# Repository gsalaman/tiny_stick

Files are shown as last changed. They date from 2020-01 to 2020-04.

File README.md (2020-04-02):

# Tiny Stick
Hardware design for a line of 8 surface-mount WS2812C LEDs

tinystick

# Configurations
## UNO (or other external processor)
You can use the 8 RGB LEDs with any Arduino capable processor.  Supply 5v, Gnd, and your Data Input via the "external input" ports on the bottom-left of the board.

You can chain together multiple sticks by using the "external output" port on the bottom-right.
## Tiny85
The board can also be populated with a tiny85.  Recommended configuration is to put a socket on U1 (top left) as to allow for the processor to be removed and programmed.  This processor connects to the data input line via Ardiuno Data pin 3 (physical pin 2 on the tiny).

There is also space on the board for a potentiometer.  The two sides are connected to power and ground, and the middle is connected to arduino pin 2 (physical pin 7).

Finally, there is a push-button, connected to Arduino pin 0 (phyical pin 5).  This input is pulled-up.

## Using External 5v Power with Tiny85
You can connect +5v and GND to the "external input" pins on the bottom left of the board to power the Tiny and LEDs.  This input is *not* gated by the power swiitch.

## Using Coin Cell
The back of the board has a spot for a coin cell holder, which can provide power to the Tiny and LEDs.  To enable this:
* connect the middle and bottom pins of the "input power select" block, either via a jumper or solder blob.
* populate the "internal power" switch on the bottom of the board (for switch control), or, if you want it "always on", put a solder jumper between the left and middle pins.

## Using the 9v (vin) input)
You can connect a 9v battery (or anything greather than 6v) to the Vin jumpers on the bottom left of the board.  This input goes through a voltage regulator to provide 5v.  To enable this:
* connect the top and middle pins of the "input power select" block, either via a jumper or solder blob.
* populate the "internal power" switch on the bottom of the board (for switch control), or, if you want it "always on", put a solder jumper between the left and middle pins.

One note:  since the switch is after the voltage regulator, the 9v battery will *always* be powering on the voltage regulator...not an ideal design.

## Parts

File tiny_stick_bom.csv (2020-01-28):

Comment | Designator | Footprint | LCSC Part Number
2812 LED | D1,D2,D3,D4,D5,D6,D7,D8 | LED-4_5050 | C114586
4.7k ohm | R1 | 603 | C23162
22uF Tant | C9 | CASE-B_3528 | C110051
AMS1117-5.0 | U2 | SOT-223 | C6187
.1 uF | C1,C2,C3,C4,C5,C6,C7,C8 | 603 | C14663

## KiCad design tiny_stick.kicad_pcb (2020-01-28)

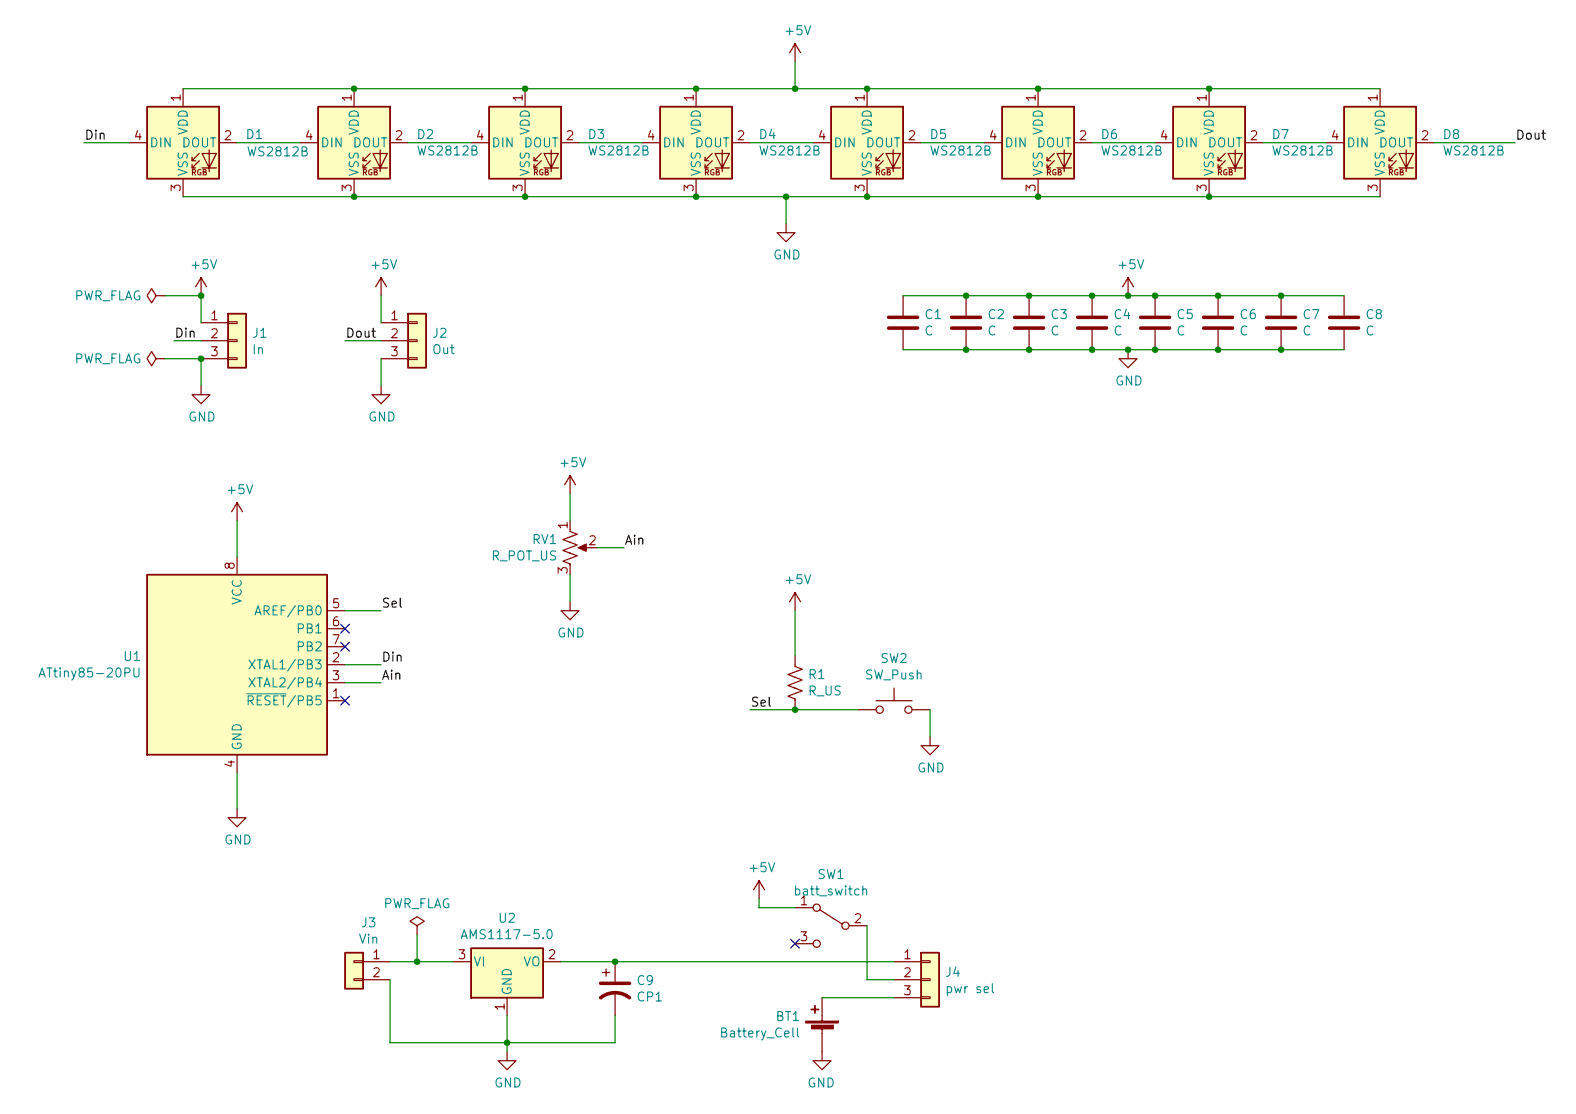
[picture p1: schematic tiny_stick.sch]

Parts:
BT1: Battery_Cell; BatteryHolder_Glenn1
C1, C2, C3, C4, C5, C6, C7, C8: C; C_0603_1608Metric
C9: CP1; CP_EIA-3528-21_Kemet-B
D1, D2, D3, D4, D5, D6, D7, D8: WS2812B; LED_WS2812B_PLCC4_5.0x5.0mm_P3.2mm
J1: In; PinHeader_1x03_P2.54mm_Vertical
J2: Out; PinHeader_1x03_P2.54mm_Vertical
J3: Vin; PinHeader_1x02_P2.54mm_Vertical
J4: pwr sel; PinHeader_1x03_P2.54mm_Vertical
R1: R_US; R_0603_1608Metric
RV1: R_POT_US; PinHeader_1x03_P2.54mm_Vertical
SW1: batt_switch; PinHeader_1x03_P2.54mm_Vertical
SW2: SW_Push; SW_PUSH-12mm
U1: ATtiny85-20PU; DIP-8_W7.62mm
U2: AMS1117-5.0; SOT-223-3_TabPin2

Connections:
+5V: C1.1, C2.1, C3.1, C4.1, C5.1, C6.1, C7.1, C8.1, D1.1 (VDD), D2.1 (VDD), D3.1 (VDD), D4.1 (VDD), D5.1 (VDD), D6.1 (VDD), D7.1 (VDD), D8.1 (VDD), J1.1, J2.1, R1.1, RV1.1, SW1.1 (A), U1.8 (VCC)
/Ain: RV1.2, U1.3 (XTAL2/PB4)
/Din: D1.4 (DIN), J1.2, U1.2 (XTAL1/PB3)
/Dout: D8.2 (DOUT), J2.2
/Sel: R1.2, SW2.1, U1.5 (AREF/PB0)
GND: BT1.2 (-), C1.2, C2.2, C3.2, C4.2, C5.2, C6.2, C7.2, C8.2, C9.2, D1.3 (VSS), D2.3 (VSS), D3.3 (VSS), D4.3 (VSS), D5.3 (VSS), D6.3 (VSS), D7.3 (VSS), D8.3 (VSS), J1.3, J2.3, J3.2, RV1.3, SW2.2, U1.4 (GND), U2.1 (GND)
unnamed: BT1.1 (+), J4.3
unnamed: C9.1, J4.1, U2.2 (VO)
unnamed: D1.2 (DOUT), D2.4 (DIN)
unnamed: D2.2 (DOUT), D3.4 (DIN)
unnamed: D3.2 (DOUT), D4.4 (DIN)
unnamed: D4.2 (DOUT), D5.4 (DIN)
unnamed: D5.2 (DOUT), D6.4 (DIN)
unnamed: D6.2 (DOUT), D7.4 (DIN)
unnamed: D7.2 (DOUT), D8.4 (DIN)
unnamed: J3.1, U2.3 (VI)
unnamed: J4.2, SW1.2 (B)

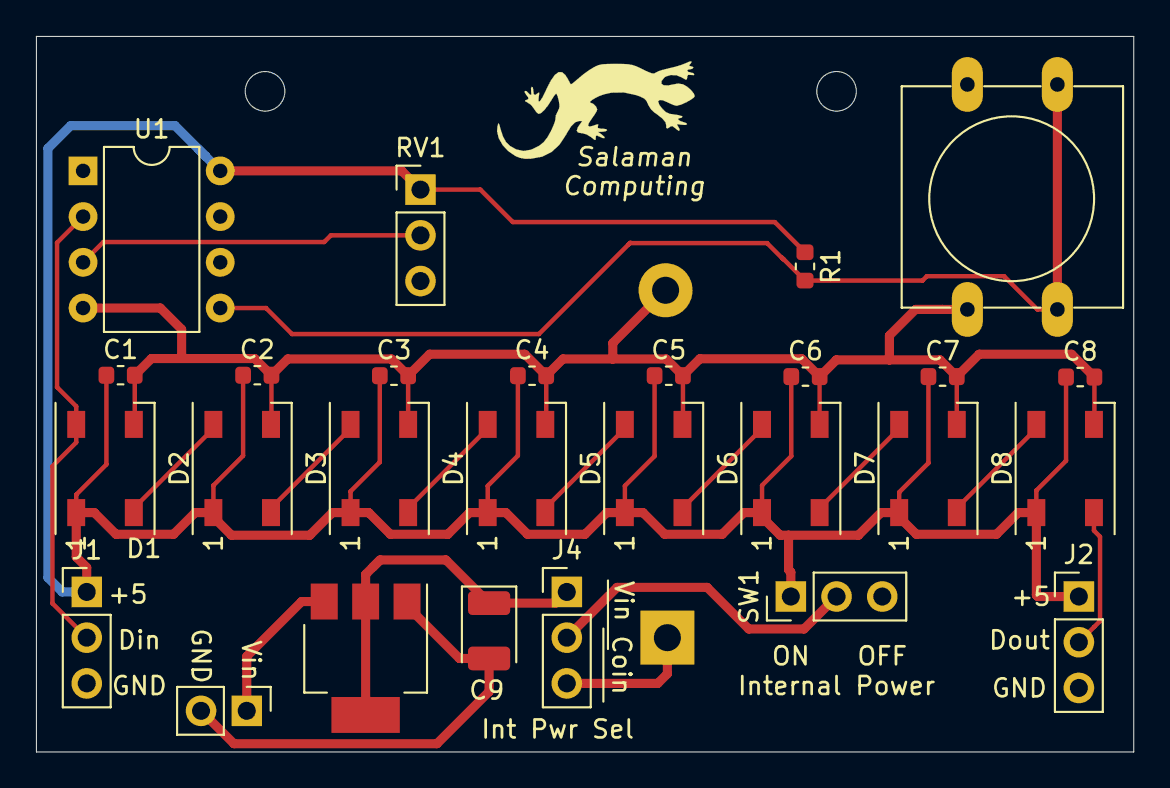
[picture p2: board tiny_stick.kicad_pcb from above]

Board: 2 copper layers, 61.0 x 39.8 mm, 28 parts (1 on the bottom side), 17 nets.
